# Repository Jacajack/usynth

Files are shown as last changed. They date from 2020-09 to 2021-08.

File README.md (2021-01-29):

# usynth



A scalable, polyphonic 8-bit AVR synthesizer employing wavetable synthesis - a summer project that exceeded my expectations.

Features:
 - PPG Wave 2.2 wavetables
 - 2 wavetable oscillators - independent voices or a single richer one
 - 2 ASR envelope generators per voice - gain, pitch and waveform modulation
 - 1 LFO per voice - triangle or square, with fade, provides pitch and waveform modulation
 - Cluster operation to provide greater polyphony (this hasn't been tested yet, but is already implemented in the source code and _should work_&trade;)
 - 1-pole lowpass filter
 - All parameters can be adjusted as MIDI controllers
 - Presets stored in flash memory
 - MIDI pitch bend support
 - MIDI velocity sensitivity
 
MIDI controller mappings can be found [here](https://github.com/Jacajack/usynth/blob/master/midictl/usynth-midictl.ctl). If you're on Linux, you can load that file directly into [midictl](https://github.com/Jacajack/midictl) and use it to control µsynth right away.

If you want to build your own µsynth, the schematic is available in the [`hw`](https://github.com/Jacajack/usynth/tree/master/hw) directory.

See demo on YouTube:<br>
Demo (https://www.youtube.com/watch?v=hL-aASeibNs "µsynth demo")

## A bit of technical background

The microcontroller is running at 20MHz (max allowed frequency at 5V). By default it's programmed to work with MCP4921 - a 12-bit SPI DAC and output samples at frequency of 28kHz. MIDI commands are received via UART0 at 31250 baud. Pins PD2, PD3 and PD4 are meant to drive status LEDs. I won't go into much detail here, because I think the source code is documented quite well.

The code is written _mostly_ in C. There are some bits in the AVR assembly language responsible for more sophisticated multiplication, but that's it. The chip is utilized pretty well with ~99% flash and ~77% RAM usage. 

The main loop is synced with timer interrupt and generates one sample per iteration. Since there are too many parameters to update all of them every sample, this work is distributed evenly accross each 21 samples. Splitting all the 'slow' code into equal pieces can be quite tricky to get right, but is definitely worth it, since it allows maximal processor time utilization.

Perhaps the most interesting bit is the synthesis process itself. The µC has waveform and wavetable data stored in flash in the same way as they were in PPG Wave (see [here](https://jacajack.github.io/music/2019/12/10/PPG-EPROM.html)). Since the AtMega328 doesn't have enough RAM to hold all the interpolated waveforms at once, everything has to be computed on the fly. In fact, I've already described this process on my blog, so I'll just refer you [there](https://jacajack.github.io/music/synths/2020/04/25/More-PPG.html).

The block diagram below represents simplified structure of a single voice. The 2 voices can be used independently or combined as a single richer one.

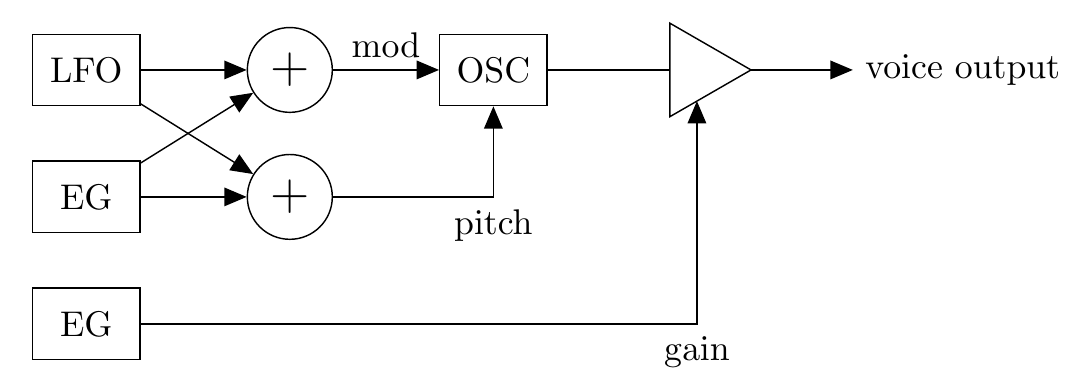
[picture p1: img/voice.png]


## Donate

If you like µsynth and want to support my future projects, you can buy me a cup of coffee below. It will be very appreciated :)



Thanks! :heart:

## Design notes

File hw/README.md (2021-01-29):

This folder contains electrical schematic of the µsynth. Based on it, you should be able to build your own equivalent very easily.

I may release the PCB design in the future.

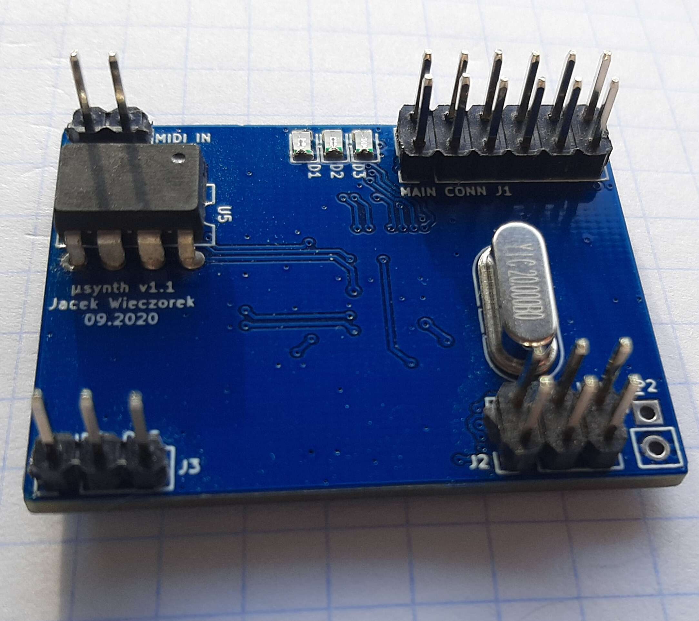
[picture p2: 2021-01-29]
img/top.jpg

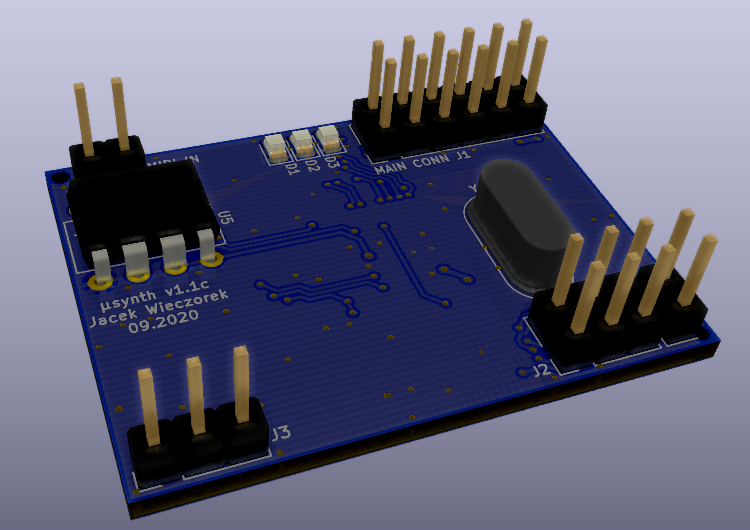
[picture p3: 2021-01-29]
img/top-kicad.png

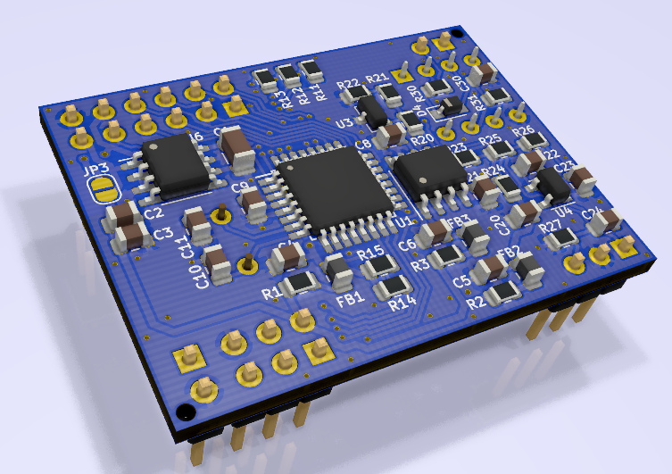
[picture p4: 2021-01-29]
img/bot-kicad.png

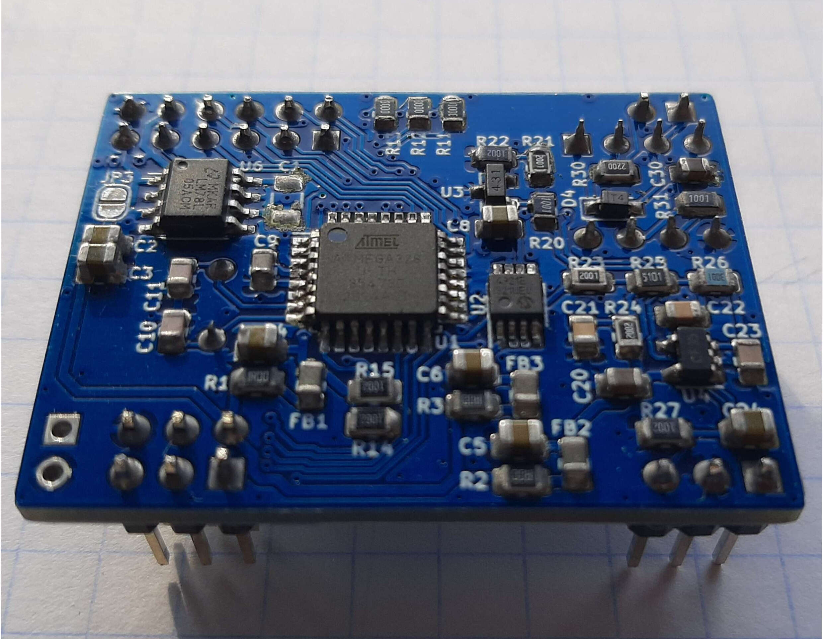
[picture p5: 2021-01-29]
img/bot.jpg

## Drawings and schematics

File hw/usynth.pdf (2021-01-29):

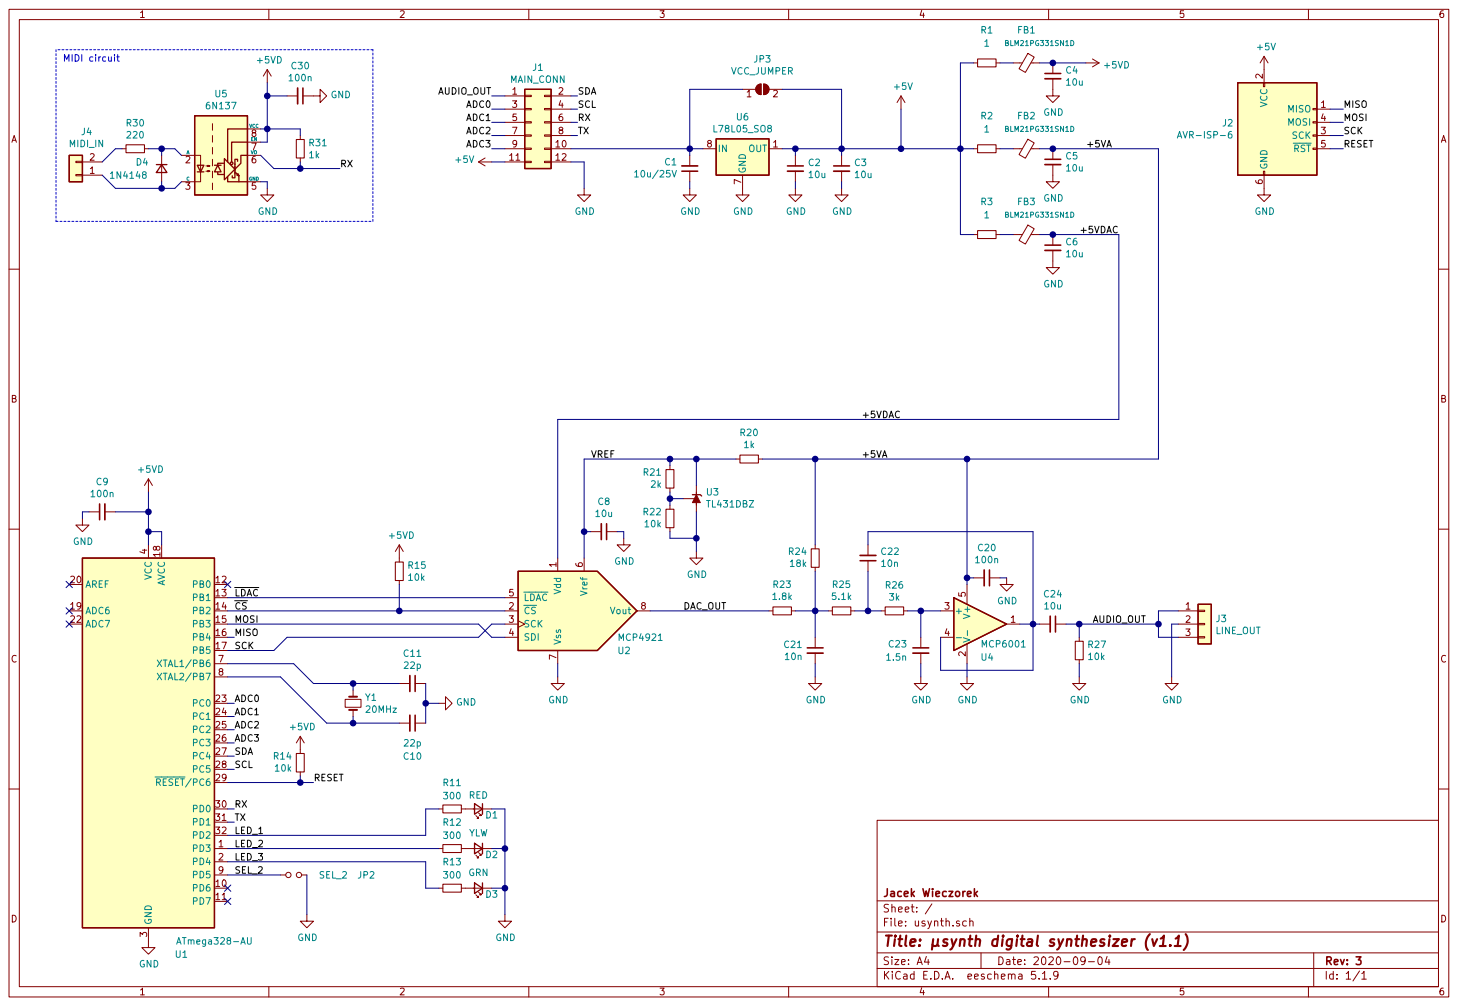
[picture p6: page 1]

2 SCK 3 MOSI 4 RST 5 GND

File: usynth.sch Sheet: / Jacek Wieczorek

Id: 1/1 Title: µsynth digital synthesizer (v1.1)

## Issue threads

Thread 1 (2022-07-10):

Program to big

KeenVox, 2022-07-10:
Hi there,

I just built your nice project but while compiling I get the message:

Program:   35206 bytes (107.4% Full)

and while flashing to the atmega I get:

ERROR: section ".text" does not fit into "flash" memory:
    0x0 + 35174 > 32768

Am I doing something wrong? Hope you can help. Would love to test this litte synth :-)

Best wishes
Keen

jpnielsen, 2022-07-16:
my attempt at a workaround

I got this:
/usr/lib/gcc/avr/5.4.0/../../../avr/bin/ld: usynth.elf section `.text' will not fit in region `text'
/usr/lib/gcc/avr/5.4.0/../../../avr/bin/ld: region `text' overflowed by 2438 bytes
collect2: error: ld returned 1 exit status

change src/makefile, line 11, CFLAGS.

Where it says: "CFLAGS = $(DEFINES) -mmcu=$(MCU) -O3 -funroll-loops -g -fdata-sections -ffunction-sections -Wl,--gc-sections -fomit-frame-pointer -faggressive-loop-optimizations -flto -mrelax -Wall -fwrapv -fstrict-aliasing"

Change -O3 to -Os and save the file.

after:

avr-size -C --mcu=atmega328p usynth.elf
AVR Memory Usage
----------------
Device: atmega328p
Program: 28056 bytes (85.6% Full)
(.text + .data + .bootloader)
Data: 1578 bytes (77.1% Full)
(.data + .bss + .noinit)
EEPROM: 699 bytes (68.3% Full)
(.eeprom)

I haven't flashed and tested - let me know if it works.

KeenVox, 2022-07-16:
It worked perfectly! Thank you so much !!

Jacajack, 2022-07-20:
Hi,

What version of GCC are you using? I noticed that the newer versions produce significantly larger binaries. The performance seems to be a bit worse too. For this reason I stick with older compiler versions when compiling the usynth code. Last time I checked, GCC 10.1.0 seemed to be good enough. By the way, you can find precompiled binaries [here](https://github.com/Jacajack/usynth/tree/master/bin).

Optimizing the code for size is obviously a good workaround to get the code into the flash, but you may find the performance unsatisfactory. It's not bound to happen, of course, but is likely. When that happens, the sound appears distorted in a distinctive manner. You might miss it at first, but once you hear the clean version it becomes obvious.

The way I debugged performance issues in the code is actually very simple. MIDI controller 111 controls "profiling" of a certain load balancing channel (one of the 21 paths of execution in the main switch statement). If there's still some time left after generating the sample, the green LED will light up. Brightness of the LED tells you how much spare time you have in each branch. When the LED is visibly flickering, it usually means that this branch is overloaded and some artifacts may be audible.

I have no idea how this happened, but somehow I have unsubscribed from the notifications from this repository and completely missed this issue. Sorry for my late response!

KeenVox, 2022-07-21:
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

Hey,
thanks for your reply. I didn't even check out that there were precompiled binaries. ^^ Will try those, in the moment it truly sounds a bit distorted.
I used the newest version of GCC through apt-get.
May really be the problem.

KeenVox, 2022-07-21:
Hm, I did try the prebuild binarys but now nothing works. :-( I used avrdude with an usbasp.

Jacajack, 2022-07-21:
That's interesting. Do you have your fuses and crystal set up properly?

KeenVox, 2022-07-22:
I think so. I installed a 20Mhz crystal with two 22pf capacitors and set the fuses to external low freq crystal and diasbeld the "divded by 8" option.

Jacajack, 2022-07-22:
Sounds good. Can you investigate whether the µC does anything at all or just doesn't respond to MIDI commands? UART problems are quite common, so it's worth ruling that out first. If you have access to an oscilloscope, you could look for look signs of life on the MOSI, SCK, OCR1A and OCR1B outputs. Does the size optimized version behave in the same way?

KeenVox, 2022-07-23:
Will check the pins.
The size optimized version works normaly with midi commands etc. no problem there.
After flashing the 10.10 precompiled binary the first led lights up. After I resett the power, it stays off and doesn't react to any inputs.

Jacajack, 2022-07-23:
Strange. In the meantime, I will double check the precompiled binaries again today.

KeenVox, 2022-07-25:
I've checked the pins. I get nothing except on the rst pin, when I play some midi notes.
With the size optimized version I get some activity on all pins.

Jacajack, 2022-07-25:
That would mean that the precompiled version is not starting at all or crashing very quickly. I've just checked both ELF files and they work just fine on my µC. My chip is ATMEGA328U-TH, fuses are E:FF, H:D1, L:FF.  I have to admit, right now I'm out of ideas what could cause that.

Would you mind sharing the size optimized binary with me? I'll see if I can get it running on my chip.

KeenVox, 2022-07-26:
I got it to work! Seemed to be a problem with the fuses after all. I used your settings an now it works.
Mine were E:FD and L:F7.
And you are right, now the sound qualitiy is much better than before. :-)

Jacajack, 2022-07-27:
Glad to hear that! I wonder whether this was caused by the brown-out detection or the different clock configuration. Anyway, I will put the my fuse bits values somewhere in the makefile or readme.

Closed 2022-07-27.

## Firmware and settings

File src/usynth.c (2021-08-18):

#include "usynth.h"
#include <avr/io.h>
#include <avr/interrupt.h>
#include <inttypes.h>
#include <stddef.h>

#include "utils.h"
#include "mul.h"
#include "midi.h"
#include "midi_program.h"
#include "midi_cc.h"
#include "ppg/ppg_osc.h"
#include "eg.h"
#include "lfo.h"
#include "filter.h"
#include "data/notes_table.h"
#include "data/env_table.h"

#ifndef F_CPU
#error F_CPU is not defined!
#endif

#ifndef F_SAMPLE
#error F_SAMPLE is not defined!
#endif

#ifndef MIDI_BAUD
#warning MIDI_BAUD is not defined! Assuming default 31250
#define MIDI_BAUD 31250
#endif

/**
	MIDI data ring buffer - written in interrupt, read in the main loop
*/
static volatile uint8_t midi_buffer[256];
static volatile uint8_t midi_wcnt = 0;

/**
	Main interrupt - sends a new sample to the DAC
*/
static volatile uint16_t dac_data = 0;
static volatile uint8_t dac_sent = 0;
ISR(TIMER1_COMPB_vect)
{
	// CS is automatically set low, but LDAC needs to be forced high
	TCCR1A |= (1 << COM1A0);
	TCCR1C |= (1 << FOC1A);
	TCCR1A &= ~(1 << COM1A1);

	const uint16_t mcp4921_conf = MCP4921_SHDN_BIT | MCP4921_GAIN_BIT | MCP4921_VREF_BUF_BIT;
	uint16_t data = mcp4921_conf | (dac_data >> 4);
	
	// Send the data via SPI
	SPDR = data >> 8;
	while (!(SPSR & (1 << SPIF)));
	SPDR = data;
	while (!(SPSR & (1 << SPIF)));
	
	// Force compare event to set CS high
	TCCR1A |= (1 << COM1B0);
	TCCR1C |= (1 << FOC1B);
	TCCR1A &= ~(1 << COM1B1);
	
	// Check incoming USART data and buffer it
	// No need for a while loop here - this interrupt
	// is frequent enough
	if (UCSR0A & (1 << RXC0))
		midi_buffer[midi_wcnt++] = UDR0;

	// Set sent flag, so the main loop can work again
	dac_sent = 1;
}

// Synth globals
static usynth_voice voices[2];
static filter1pole filter;
static int8_t filter_cutoff;

// MIDI
static midi_status midi;
static uint8_t poly_mode = 1;
static uint8_t midi_voice_offset = 0;

// For mapping MIDI CC values to uint8_t and int8_t 
#define MIDI_CTL(x) (midi.control[(x)])
#define MIDI_CTL_S8(x) (((int8_t)(MIDI_CTL((x))) - 64) << 1)
#define MIDI_CTL_U8(x) ((MIDI_CTL((x))) << 1)
#define MIDI_CTL_BOOL(x) (MIDI_CTL(x) != 0)

/**
	Updates voice state based on MIDI control parameters (part 1)
	\param cc_set determines from which MIDI CC set to update
*/
static inline void voice_update_cc_1(usynth_voice *v, uint8_t cc_set) __attribute__((always_inline));
static inline void voice_update_cc_1(usynth_voice *v, uint8_t cc_set)
{
	v->base_wave = MIDI_CTL_S8(MIDI_OSC_BASE_WAVE(cc_set));
	v->eg_mod_int = MIDI_CTL_S8(MIDI_EG_MOD_INT(cc_set));
	v->lfo_mod_int = MIDI_CTL_S8(MIDI_LFO_MOD_INT(cc_set));

	v->amp_eg.attack  = pgm_read_word(env_table + MIDI_CTL(MIDI_AMP_A(cc_set)));
	v->amp_eg.sustain = MIDI_CTL_U8(MIDI_AMP_S(cc_set));
	v->amp_eg.release = pgm_read_word(env_table + MIDI_CTL(MIDI_AMP_R(cc_set)));
	v->amp_eg.sustain_enabled = MIDI_CTL(MIDI_AMP_ASR(cc_set));

	v->mod_eg.attack  = pgm_read_word(env_table + MIDI_CTL(MIDI_EG_A(cc_set)));
	v->mod_eg.sustain = MIDI_CTL_U8(MIDI_EG_S(cc_set));
	v->mod_eg.release = pgm_read_word(env_table + MIDI_CTL(MIDI_EG_R(cc_set)));
	v->mod_eg.sustain_enabled = MIDI_CTL(MIDI_EG_ASR(cc_set));
}

/**
	Updates voice state based on MIDI control parameters (part 2)
	\param cc_set determines from which MIDI CC set to update
*/
static inline void voice_update_cc_2(usynth_voice *v, uint8_t cc_set)
{
	v->eg_pitch_int = (int8_t)MIDI_CTL(MIDI_EG_PITCH_INT(cc_set)) - 64;
	v->lfo_pitch_int = (int8_t)MIDI_CTL(MIDI_LFO_PITCH_INT(cc_set)) - 64;

	v->lfo.step = MIDI_CTL_U8(MIDI_LFO_RATE(cc_set)) << 1;
	v->lfo.waveform = MIDI_CTL(MIDI_LFO_WAVE(cc_set));
	v->lfo.fade_step = pgm_read_word(env_table + MIDI_CTL(MIDI_LFO_FADE(cc_set)));

	// Loads wavetable when it changes
	if (v->wavetable_number != MIDI_CTL(MIDI_OSC_WAVETABLE(cc_set)))
	{
		v->wavetable_number = MIN(MIDI_CTL(MIDI_OSC_WAVETABLE(cc_set)), PPG_WAVETABLE_COUNT - 1);

		// Write back to the MIDI controls array, so the wavetable
		// is not reloaded over and over if it's out of range
		MIDI_CTL(MIDI_OSC_WAVETABLE(cc_set)) = v->wavetable_number;

		ppg_osc_load_wavetable(&v->osc, v->wavetable_number);
	}
}

/**
	Updates voice's gate - retriggers LFO and EGs and propagates gate value to them.
	\param cc_set determines from which MIDI CC set to update
	\param midi_voice determines polyphony voice ID to use
*/
static inline void voice_update_gate(usynth_voice *v, uint8_t cc_set, uint8_t midi_gate)
{
	// Executed once on keypress
	if (midi_gate & MIDI_GATE_TRIG_BIT)
	{
		// Reset EGs
		v->amp_eg.status = USYNTH_EG_IDLE;
		v->amp_eg.value = 0;
		v->mod_eg.status = USYNTH_EG_IDLE;
		v->mod_eg.value = 0;
		
		// Reset oscillator
		v->osc.phase = 0;

		// Reset LFO
		v->lfo.fade = 0;
		if (MIDI_CTL(MIDI_LFO_SYNC))
			usynth_lfo_sync(&v->lfo);
	}

	v->amp_eg.gate = midi_gate;
	v->mod_eg.gate = midi_gate;
	v->lfo.gate = midi_gate;
}

/**
	Updates voice's frequency based on MIDI note and all modulation sources
	\param cc_set determines from which MIDI CC set to update
	\param midi_voice determines polyphony voice ID to use
*/
static inline void voice_update_note(usynth_voice *v, uint8_t cc_set, uint8_t midi_note) __attribute__((always_inline));
static inline void voice_update_note(usynth_voice *v, uint8_t cc_set, uint8_t midi_note)
{
	int16_t note = (int16_t)midi_note + MIDI_CTL(MIDI_OSC_PITCH(cc_set)) - 64 - 4; // Subtract 4 here intead of subtracting 128 later
	note <<= 5; // Now we operate on 100/32 cents
	note += (int16_t)(midi.pitchbend >> 7) + MIDI_CTL(MIDI_OSC_DETUNE(cc_set));
	note += (v->eg_pitch_int * (int8_t)(v->mod_eg.output >> 9)) >> 3;
	note += (v->lfo_pitch_int * (int8_t)(v->lfo.output >> 8)) >> 4;
	
	// Equivalent of CLAMP(note, 0, 128 * 32 - 1)
	note = note < 0 ? 0 : note;
	note &= 4095;
	v->osc.phase_step = pgm_read_delta_word(notes_table, note);
}

/**
	Updates currently used waveform
*/
static inline void voice_update_mod(usynth_voice *v)
{
	int16_t mod = v->base_wave;
	mod += (v->eg_mod_int * (int8_t)(v->mod_eg.output >> 9)) >> 5;
	mod += (v->lfo_mod_int * (int8_t)(v->lfo.output >> 8)) >> 6;

	// The -128 - 127 range is mapped to 0 - 64
	mod = 32 + (mod >> 2);
	v->osc.wave = CLAMP(mod, 0, PPG_DEFAULT_WAVETABLE_SIZE - 1);
}

/**
	Updates global/common synth state
*/
static inline void update_global_1(void)
{
	// Resets phase of all LFOs
	if (MIDI_CTL(MIDI_LFO_RESET))
	{
		MIDI_CTL(MIDI_LFO_RESET) = 0;
		usynth_lfo_sync(&voices[0].lfo);
		usynth_lfo_sync(&voices[1].lfo);	
	}

	// Handle ping requests
	if (MIDI_CTL(MIDI_PING))
	{
		// Transmit one byte of ping response
		while (!(UCSR0A & (1 << UDRE0)));
		UDR0 = MIDI_CTL(MIDI_PING);
		MIDI_CTL(MIDI_PING) = 0;
	}

	// Filter control
	filter_cutoff = MIDI_CTL(MIDI_CUTOFF) >> 1;

	// Clear 'triggered' gate bits
	midi_clear_trig_bits(&midi);
}

/**
	Updates global state - handles mono/poly switching and cluster operation
*/
static inline void update_global_2(void)
{
	// Mono/poly and cluster logic
	uint8_t cluster_size = CLAMP(MIDI_CTL(MIDI_CLUSTER_SIZE), 1, MIDI_MAX_VOICES / 2);
	uint8_t cluster_id = MIN(MIDI_CTL(MIDI_CLUSTER_ID), cluster_size - 1);
	poly_mode = MIDI_CTL(MIDI_POLY) != 0;
	midi.voice_count = (poly_mode + 1) * cluster_size;
	midi_voice_offset = (poly_mode + 1) * cluster_id;
}

int main(void)
{
	// LEDs
	DDRD |= (1 << LED_1_PIN) | (1 << LED_2_PIN) | (1 << LED_3_PIN);
	
	// 10 MHz SPI Master, DAC IO
	PORTB |= (1 << LDAC_PIN) | (1 << CS_PIN);
	DDRB |= (1 << LDAC_PIN) | (1 << CS_PIN) | (1 << MOSI_PIN) | (1 << SCK_PIN);
	SPCR = (1 << SPE) | (1 << MSTR);
	SPSR = (1 << SPI2X);
	
	/*
		TIMER 1 - CTC mode, F_CPU

		- Clear OC1B (CS) on compare
		- Clear OC1A (LDAC) on compare
		- COMP1B ISR active

		Event:    COMPB       FORCE
		__   _______|    ISR    |__________
		CS          |___________|

		Event:      FORCE           COMPA
		____          |_______________|
		LDAC _________|               |____
	*/
	TCCR1A = (1 << COM1A1) | (1 << COM1B1);
	TCCR1B = (1 << WGM12) | (1 << CS10);
	TIMSK1 = (1 << OCIE1B);
 	OCR1A = F_CPU / F_SAMPLE - 1;
 	OCR1B = 4; // Determines LDAC pulse width (must be over 100ns)
	
	// USART0 - MIDI, 8 bit data, 1 bit stop, no parity
	UBRR0 = F_CPU / 16 / MIDI_BAUD - 1;
	UCSR0B = (1 << RXEN0) | (1 << TXEN0);
	UCSR0C = (1 << UCSZ00) | (1<< UCSZ01);
	
	// -------------- HW init done

	// Force wavetable reload by storing a fake number
	voices[0].wavetable_number = 255;
	voices[1].wavetable_number = 255;

	midi_init(&midi, 2);
	midi_program_load(&midi, 0);
	MIDI_CTL(MIDI_CLUSTER_SIZE) = 1;
	MIDI_CTL(MIDI_CLUSTER_ID) = 0;

	sei();

	// The main loop
	uint8_t load_balancer_cnt = 0;
	uint8_t midi_rcnt = 0;
	while (1)
	{
		/*
			Distribute workload evenly across each 21 samples
			
			31250 / 8 / 28000 * 20 = ~2.92 which means that reading
			3 MIDI data bytes in the loop is sufficient
		*/
		switch (load_balancer_cnt++)
		{
			// Process MIDI byte
			case 0:
				if (midi_rcnt != midi_wcnt) midi_process_byte(&midi, midi_buffer[midi_rcnt++], 0);
				break;

			// Process MIDI byte
			case 1:
				if (midi_rcnt != midi_wcnt) midi_process_byte(&midi, midi_buffer[midi_rcnt++], 0);
				break;

			// Process MIDI byte
			case 2:
				if (midi_rcnt != midi_wcnt) midi_process_byte(&midi, midi_buffer[midi_rcnt++], 0);
				break;

			// Update from MIDI (1/2) (Voice 0)
			case 3:
				voice_update_cc_1(&voices[0], 0);
				break;

			// Update from MIDI (2/2) (Voice 0)
			case 4:
				voice_update_cc_2(&voices[0], 0);
				break;

			// Update from MIDI (1/2) (Voice 1)
			case 5:
				if (poly_mode)
					voice_update_cc_1(&voices[1], 0);
				else
					voice_update_cc_1(&voices[1], 1);
				break;

			// Update from MIDI (2/2) (Voice 1)
			case 6:
				voice_update_cc_2(&voices[1], !poly_mode);
				break;

			// Update control parameters 0, 1
			case 7:
				voice_update_gate(&voices[0], 0, midi.voices[midi_voice_offset].gate);
				voice_update_gate(&voices[1], !poly_mode, midi.voices[midi_voice_offset + poly_mode].gate);
				break;
			
			// Update frequency (Voice 1)
			case 8:
				voice_update_note(&voices[0], 0, midi.voices[midi_voice_offset].note);
				break;

			// Update frequency (Voice 2)
			case 9:
				if (poly_mode)
					voice_update_note(&voices[1], 0, midi.voices[midi_voice_offset + poly_mode].note);
				else
					voice_update_note(&voices[1], 1, midi.voices[midi_voice_offset + poly_mode].note);
				break;

			// Update globals (1/2)
			case 10:	
				update_global_1();
				break;

			// Update globals (2/2)
			case 11:
				update_global_2();
				break;
				
			// AMP EG 0
			case 12:
				usynth_eg_update(&voices[0].amp_eg);
				break;

			// AMP EG 1
			case 13:
				usynth_eg_update(&voices[1].amp_eg);
				break;

			// MOD EG 0 
			case 14:
				usynth_eg_update(&voices[0].mod_eg);
				break;

			// MOD EG 1
			case 15:
				usynth_eg_update(&voices[1].mod_eg);
				break;

			// LFO 0
			case 16:
				usynth_lfo_update(&voices[0].lfo);
				break;

			// LFO 1
			case 17:
				usynth_lfo_update(&voices[1].lfo);
				break;

			// Update modulation 0
			case 18:
				voice_update_mod(&voices[0]);
				break;

			// Update modulation 1
			case 19:
				voice_update_mod(&voices[1]);
				break;

			// LEDs and counter reset
			case 20:
				if (voices[0].amp_eg.output >> 8)
					PORTD |= (1 << LED_RED_PIN);
				else
					PORTD &= ~(1 << LED_RED_PIN);

				if (voices[1].amp_eg.output >> 8)
					PORTD |= (1 << LED_YLW_PIN);
				else
					PORTD &= ~(1 << LED_YLW_PIN);

				load_balancer_cnt = 0;
				break;
		}

		ppg_osc_update(&voices[0].osc);
		ppg_osc_update(&voices[1].osc);

		// Mixing
		uint16_t x0, x1;
		MUL_U16_U16_16H(x0, voices[0].osc.output, voices[0].amp_eg.output);
		MUL_U16_U8_16H(x0, x0, midi.voices[midi_voice_offset].velocity << 1);
		MUL_U16_U16_16H(x1, voices[1].osc.output, voices[1].amp_eg.output);
		MUL_U16_U8_16H(x1, x1, midi.voices[midi_voice_offset + poly_mode].velocity << 1);

		// Filter
		int16_t x = (x0 >> 1) + (x1 >> 1) - 32768;
		x = filter1pole_feed(&filter, filter_cutoff, x);

		// Output sample
		dac_data = x + 32768;
		
		// Wait for the 'sent' flag and clear it
		while (!dac_sent)
		{
			if (load_balancer_cnt == MIDI_CTL(MIDI_DEBUG_CHANNEL)) PORTD |= (1 << LED_GRN_PIN);
		}
		PORTD &= ~(1 << LED_GRN_PIN);
		dac_sent = 0;
	}
}

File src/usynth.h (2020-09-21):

#ifndef USYNTH_H
#define USYNTH_H

#include "ppg/ppg_osc.h"
#include "eg.h"
#include "lfo.h"

// LED IO defs
#define LED_1_PIN 2
#define LED_2_PIN 3
#define LED_3_PIN 4
#define LED_RED_PIN LED_1_PIN
#define LED_YLW_PIN LED_2_PIN
#define LED_GRN_PIN LED_3_PIN

// DAC IO defs
#define LDAC_PIN  1
#define CS_PIN    2
#define MOSI_PIN  3
#define SCK_PIN   5

// DAC config bits
#define MCP4921_DAC_AB_BIT   (1 << 15)
#define MCP4921_VREF_BUF_BIT (1 << 14)
#define MCP4921_GAIN_BIT     (1 << 13)
#define MCP4921_SHDN_BIT     (1 << 12)

/**
	A single synthesizer voice
*/
typedef struct usynth_voice
{
	ppg_osc osc;
	usynth_eg amp_eg;
	usynth_eg mod_eg;
	usynth_lfo lfo;
	int8_t base_wave;
	int8_t eg_mod_int;
	int8_t lfo_mod_int;
	int8_t eg_pitch_int;
	int8_t lfo_pitch_int;
	uint8_t wavetable_number;
} usynth_voice;


#endif

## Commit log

2020-09-01 Add EGs and basic (and broken) polyphony
    [usynth.c]
2020-09-03 Properly re-trigger EGs and add a 1-pole LP filter
2020-09-03 Improve work distribution across samples
2020-09-03 Fix bug where the synthesizer would lag upon receiving any MIDI controls when the wavetable number was over 27. Make MIDI velocity affect note volume. Remove old code.
    [usynth.c]
2020-09-03 Buffer MIDI data and only process it in the load balancer to avoid audible artifacts
    [usynth.c]
2020-09-05 Fix issues with modulation
    [usynth.c]
2020-09-05 Implement pitch bend and detune based on more precise MIDI note table
2020-09-08 Split oscillator, EG and LFO banks
    [lfo.h, usynth.c]
2020-09-09 Fix modulation value clamp
    [usynth.c]
2020-09-12 Move MIDI data buffering to the main interrupt. This fixes any potential hardware buffer overruns caused by slow code in the main loop.
    [usynth.c]
2020-09-17 Add working (but ugly) code for switching to mono mode. Remove config.h. Improve makefile. Fix pgm_read_delta_word(). Lesser cleanups
    [lfo.h, usynth.c]
2020-09-18 Add MIN, MAX and CLAMP. Remove invalid +1 offset from oscillator phase step. Move usynth_voice declaration to usynth.h
    [usynth.c, usynth.h]
2020-09-18 Fix audible clicking generated by parsing MIDI messages.
    Implement fixed-size MIDI ring buffer. Move midi_process_byte to header file, so it can be inlined better. Move MIDI program loading functions to midi.c - now only program data is left in midi_program.c.
    [usynth.c]
2020-09-21 Implement pitch modulation by LFO and EG
2021-08-18 Minimize LDAC jitter
2022-07-27 Add target for programming fuse bits (close #1)

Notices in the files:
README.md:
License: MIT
